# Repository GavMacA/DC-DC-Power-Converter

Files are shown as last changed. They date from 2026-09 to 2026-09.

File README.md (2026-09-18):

# DC-DC-Power-Converter
Complete design of a DC-DC power converter capable of powering a device using a USB-C cable powered by a DC source while adhering to USB Power Delivery specs
The specifications for the design were split in to two domains:

Static:
- Input Voltage Range = 7.5V - 24V
- Output Voltage Range = 5V - 15V
- Max Output Current = 3A
- Max peak-to-peak variation in the winding less than 25% of the max output current
- Max output voltage variation +/- 25mV

Dynamic:
- Response Time less than 1.5ms (to within 5%) during a step from 5V to 12V (Vin = 24V, Rout = 4Ohms)
- Overshoot: Less than 5% during voltage steps
- Load Step Recovery: Voltage error less than 100mV within 1ms after load transition (Vout=5V, Vin=24V, R[load] passes from 3 kOhms to 4 Ohms)
- Max 2.5V overshoot during a load step (from 3A to 0A)

# Project Structure

```bash
DC-DC Power Converter/
├── README.md
├── docs/
│   ├── B5_BALHI_THENOZ_MACAONGHUSA_simu_buck_CREATE_BF.slx
│   ├── B5_BALHI_THENOZ_MACAONGHUSA_simu_buck_CREATE_BO.slx
│   └── main.c   (Microcontroller code)
├── images/
│   ├── BUCK_CL_Simulink
│   ├── BUCK_OL_SIMULINK
│   ├── PCB_Bottom_Lyer.png
│   ├── PCB_Top_Layer.png
│   ├── Physical_Board_Bottom_Layer.jpeg
│   └── Physical_Board_Top_Layer.jpeg
└── Altium/
│   ├── A4_INSAGE_01.SchDoc
│   ├── A4_INSAGE_02.SchDoc
│   ├── A4_INSAGE_03.SchDoc
│   ├── Altium CREATE 2026.PrjPcb
│   ├── Altium_CREATE_2026.IntLib
│   └── PCB1_INSAGE.PcbDoc
```

## Design and size closed loop and open loop Buck Converter using MATLAB Simulink

Using real world RS components available online we sized components to achieve the above specifications with an approximate efficiency of 90% for the open loop design.

<div align="center">

Open Loop Buck

</div>

The closed loop design incorporated an adjustable PID regulator to respond to a change in load size or target output voltage.

<div align="center">

Closed Loop Buck

</div>

## Mapping and Routing of PCB using Altium Designer

<div align="center">

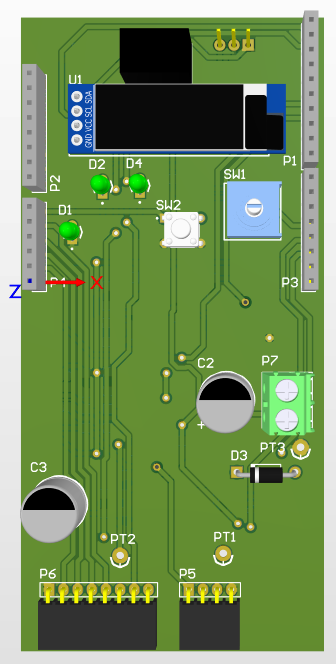
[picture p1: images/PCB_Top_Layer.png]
PCB Top Layer


**PCB Top Layer**

</div>

<div align="center">

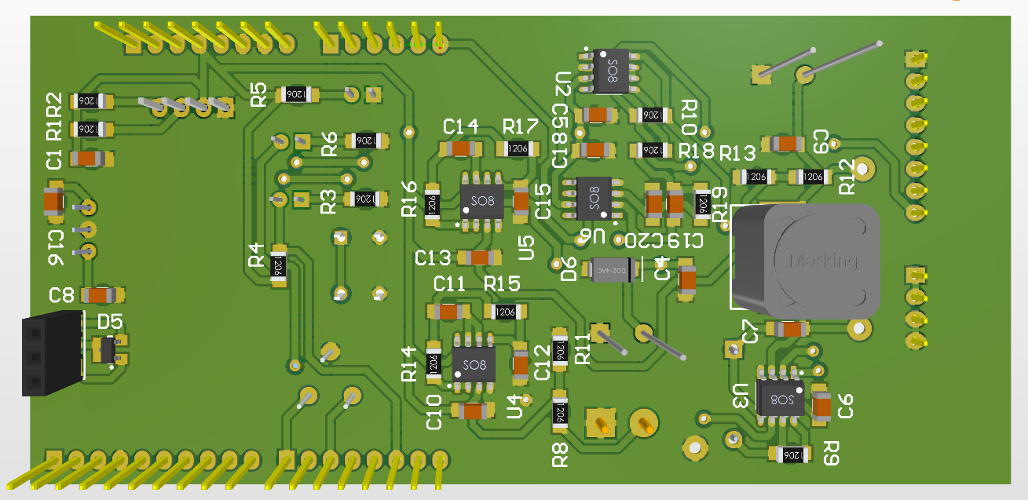
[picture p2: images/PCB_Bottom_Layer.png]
PCB Bottom Layer


**PCB - Bottom Layer**

</div>

## Soldering Standardised routing provided by module coordinators

<div align="center">

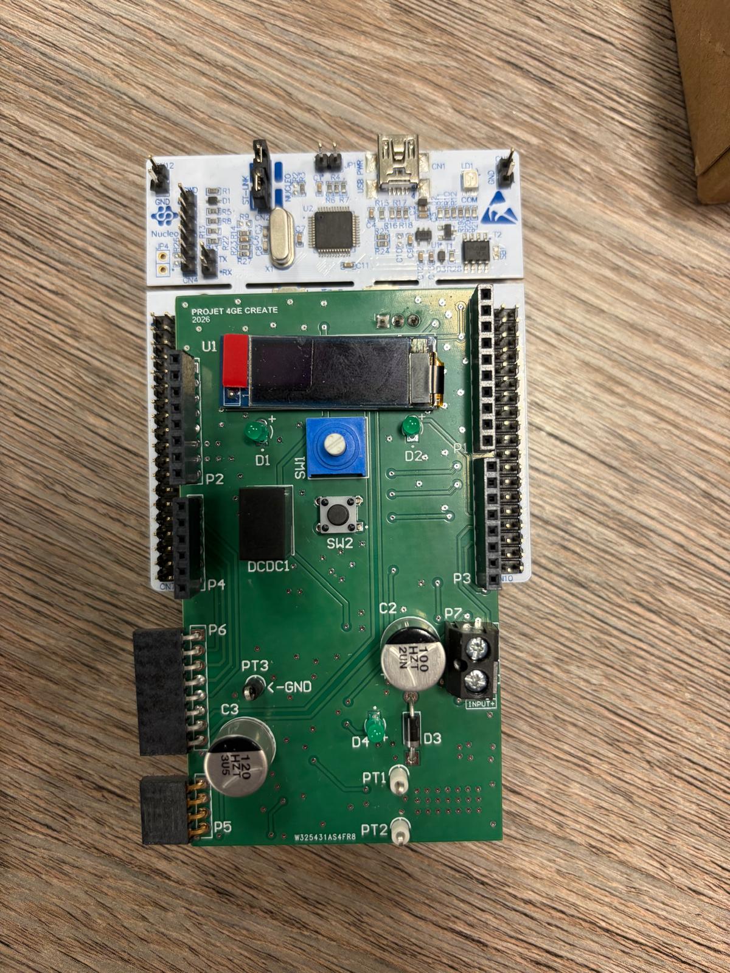
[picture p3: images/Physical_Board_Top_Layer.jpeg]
Board Top Layer


**Board Top Layer**

</div>

<div align="center">

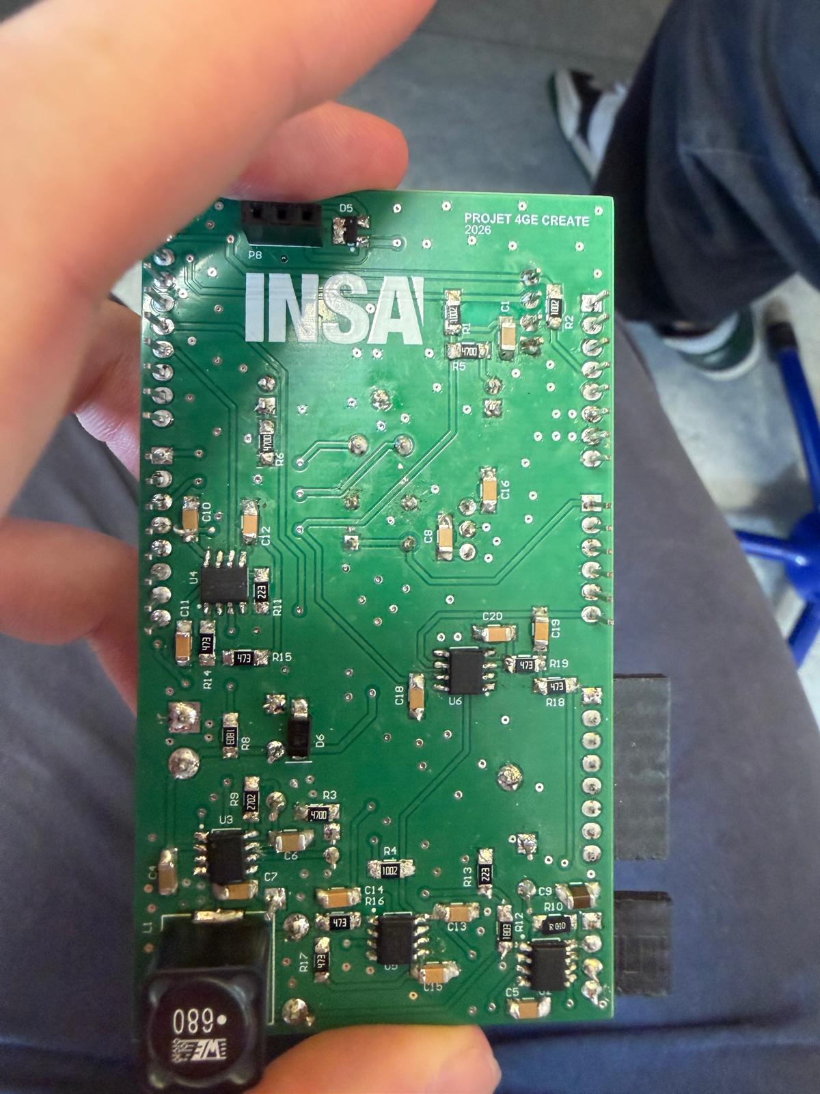
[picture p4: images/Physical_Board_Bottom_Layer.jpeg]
Board Bottom Layer


**Board - Bottom Layer**

</div>

## Modifying STM32Cube microcontroller code using C

The project was generated in STM32CubeIDE/CubeMX; our work was confined to the USER CODE sections of main.c. The final stage of the project gave us several different ideas to focus on when adapting the code. Thus it must be acknowledged that this code is an incomplete prototype. Our focuses were User Interface/Controls, PWM Control, Open and Closed Loop modes and Power Delivery Object mode (PI control used for CL and PDO).

The User interface was implemented using an OLED screen, rotary encoder and button. It offers 4 menus: Display of measurements (Vin, Vout, Iout), Control type (OL, CL, PDO), OL setpoint, CL setpoint (set desired output voltage).

- Open Loop - Calculates duty cycle each period using the current input voltage and the user-selected output voltage, with no feedback from the output.
- Closed Loop - Constantly updates the duty cycle using PI in response to fluctuations in the load size to maintain desired voltage output.
- PDO - The controller negotiates the USB-C contract and the firmware reads the agreed profile (5/9/12/15V) and then the PI maintains this level

Direct Memory Access is used for efficient sampling and the PWM output. The ADC by the internal timer and writes its three channels straight to memory. The PWM duty cycle is streamed from a double-buffered array so it can be updated without disturbing the running output. It is 8 bits (0-255) due to the timer's 256-count period.To reduce computational overhead the PI controller coefficents were scaled up in order to avoid floating point values instead completing integer calculations. 

**Notes/Limitations**
- Much of the code's comments are in French as this project was completed during an ERASMUS programme.
- Sections not chosen under the scope: Energy and Power calculations; overload protection; output filtering

# My Contributions
Most tasks were completed collaboratively, the following our sections I contributed to directly.

- Simulink - Design and testing of open loop buck converter
- Altium - Schematic connections, mapping of PCB layout
- PCB - Soldered surface mounted and through-hole components
- Microcontroller code (C) - PWM configuration and non-technical writing of User-interface 

# Contributors
Matteo Thenoz

Guillaume Balhi

Gavin Mac Aonghusa

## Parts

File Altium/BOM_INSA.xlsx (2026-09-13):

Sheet: BOM Report
Nomenclature
Source : |  | Field=DataSourceFileName
Projet : |  | Field=ProjectFileName
Désignation | Description | SchLib_Id | PcbLib_Id | Valeur | Puissance | Fournisseur 1 | Fournisseur 2
Date d'édition : | 2020-12-18 | 10:35:19

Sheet: Project Information
Project Full Path | Field=ProjectFullPath
Project Filename | Field=ProjectFileName
Variant Name | Field=VariantName
Data-Source Filename | Field=DataSourceFileName
Data-Source Full Path | Field=DataSourceFullPath
Title | Field=Title
Total Quantity | Field=TotalQuantity
Report Time | Field=ReportTime
Report Date | Field=ReportDate
Report Date & Tine | Field=ReportDateTime
Output Name | Field=OutputName
Output Type | Field=OutputType
Output Generator Name | Field=GeneratorName
Output Generator Description | Field=GeneratorDescription

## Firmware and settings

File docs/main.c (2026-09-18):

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
/* Includes ------------------------------------------------------------------*/
#include "main.h"

/* USER CODE BEGIN Includes */
#include <string.h>
#include <stdio.h>
#include <stdbool.h>
#include "ssd1306/ssd1306.h"
/* USER CODE END Includes */

/* USER CODE BEGIN PD */
#define ADC_BUF_LEN 3

#define PWM_BUFFER_SIZE 32
#define PWM_HALFBUFFER_SIZE 16
#define DITHER_RES 8

enum rotary_direction {
	DIRECTION_NONE,
	DIRECTION_CW,
	DIRECTION_CCW,
	NUM_OF_DIRECTIONS
};

/* USER CODE END PD */

ADC_HandleTypeDef hadc;
DMA_HandleTypeDef hdma_adc;

I2C_HandleTypeDef hi2c1;

TIM_HandleTypeDef htim2;
TIM_HandleTypeDef htim22;
DMA_HandleTypeDef hdma_tim2_ch2;

UART_HandleTypeDef huart2;

/* USER CODE BEGIN PV */
static uint8_t rotary_state;
static uint8_t rotary_counter = 0;
static int8_t rotary_direction = DIRECTION_NONE;

uint16_t adc_buf[ADC_BUF_LEN];

// Tramage (dithering)
uint16_t pwm_buffer[PWM_BUFFER_SIZE];
uint8_t pwm_pulse = 0;

//Asservissement / regulation
int32_t integration_sum = 0.0;
uint32_t pwm_pulse_BF = 0;
uint8_t Vref_BF = 0;
// sur chaque valeurs des coeficiant de calcul, on applique un facteur 10 puissance 10 pour manipuler des int
int32_t dt = 256; //la periode d'échantillonage
int32_t Kp  = 500000;
int32_t Ki = 400000;

//variables des mesures de l'ADC
float vin_value =  0.0;
float vout_value = 0.0;
float iout_value = 0.0;

/* USER CODE END PV */

void SystemClock_Config(void);
static void MX_GPIO_Init(void);
static void MX_DMA_Init(void);
static void MX_ADC_Init(void);
static void MX_I2C1_Init(void);
static void MX_USART2_UART_Init(void);
static void MX_TIM2_Init(void);
static void MX_TIM22_Init(void);
/* USER CODE BEGIN PFP */

// State management
void Set_Next_Mode(void);
void Set_Previous_Mode(void);

// Human interface
void Update_Display(void);
bool Button_Pushed(){
	if(HAL_GPIO_ReadPin(GPIOA, Button_Pin) == 0){
		return true;
	}else{
		return false;
	}
}


// USB Power Delivery requests
uint8_t Read_USB_PDO(void);
void Test_STUSB_I2C(void);
void Set_STUSB_Available_Profiles(uint8_t num_profiles);

// Voltage controller
int32_t Compute_control_input(int32_t y_setpoint, int32_t y_value);
void TransferComplete(DMA_HandleTypeDef *hdma);
void TransferHalfComplete(DMA_HandleTypeDef *hdma);

/* USER CODE END PFP */

/**
  * @brief  The application entry point.
  * @retval int
  */
int main(void)
{

  /* MCU Configuration--------------------------------------------------------*/

  /* Reset of all peripherals, Initializes the Flash interface and the Systick. */
  HAL_Init();

  /* Configure the system clock */
  SystemClock_Config();

  /* Initialize all configured peripherals */
  MX_GPIO_Init();
  MX_DMA_Init();
  MX_ADC_Init();
  MX_I2C1_Init();
  MX_USART2_UART_Init();
  MX_TIM2_Init();
  MX_TIM22_Init();
  /* USER CODE BEGIN 2 */

	// Initialize screen
	ssd1306_Init();
	ssd1306_Fill(Black);
	ssd1306_UpdateScreen();

	//  HAL_TIM_PWM_Start(&htim2,TIM_CHANNEL_3);
	HAL_ADC_Start_DMA(&hadc, (uint32_t*) adc_buf, ADC_BUF_LEN);

	// Start PWM timer
	HAL_TIM_PWM_Start_DMA(&htim2, TIM_CHANNEL_2, (uint32_t*) pwm_buffer, PWM_BUFFER_SIZE);

	// Start main timer
	htim2.hdma[TIM_DMA_ID_CC2]->XferCpltCallback = TransferComplete;
	htim2.hdma[TIM_DMA_ID_CC2]->XferHalfCpltCallback = TransferHalfComplete;
	HAL_TIM_Base_Start_IT(&htim22);

	// Switch off user LED
	HAL_GPIO_WritePin(LED_GPIO_Port, LED_Pin, 0);

  /* USER CODE END 2 */

  /* Infinite loop */
  /* USER CODE BEGIN WHILE */

	// TODO
	// 1.1 Menu et navigation


	//déclaration des variables utilisateur
	uint8_t Vout_BO = 0;
	uint8_t Vout_BF = 0;
	uint8_t type_commande = 2; // 0 = BO, 1 = BF, 2 = PDO

	// définition des variable pour l'affichage des mesures
	int vin_value_int_u = 0;
	int vin_value_int_d = 0;

	int vout_value_int_u = 0;
	int vout_value_int_d = 0;

	int iout_value_int_u = 0;
	int iout_value_int_d = 0;


	//déclaration des variable définissant les modes d'utilisations des différents menus (mode 0 = affichage, mode 1 = modification)
	uint8_t mode = 0;
	uint8_t menu = 0;

	//déclaration du numéro de menu max ategnable
	int menu_max = 3;

	//déclaration des variables texte que l'on affichera sur l'écran
	char line1_str[20] = {0};
	char line2_str[20] = {0};
	char line3_str[20] = {0};

	while (1)
	{
    /* USER CODE END WHILE */

    /* USER CODE BEGIN 3 */

		//les lignes de code suivante permettent de gérer les différent menus de l'IHM
		//dans l'ordre, les menus permettent de :
		//afficher les valeurs mesurée des tensions et courants
		//selectionner le type de commande que l'on veut pour notre convertisseur (BO, BF ou PDO)
		//définir les paramètre de la commande en Boucle ouverte
		//définir les paramètre de la commande en Boucle fermé

		//L'interface à 2 modes différent, un mode de sélection de menu, et un mode de définission des paramètres.

		//pour le premier mode de sélection des menus :
		if(mode == 0){
			// premier menu, affichage du courant et des tensions mesurées
			if(rotary_counter == 0){
				sprintf(line1_str, "affichage mesures ", rotary_counter);
				sprintf(line2_str, "Ve:%02u,%02u Vs:%02u,%02u ", vin_value_int_u, vin_value_int_d, vout_value_int_u, vout_value_int_d);
				sprintf(line3_str, "Io:%02u,%03u         ", iout_value_int_u, iout_value_int_d);
			}
			// deuxième menu, selection du type de commande
			if(rotary_counter == 1){

				sprintf(line1_str, "Selection commande");
				sprintf(line2_str, "                   ");

				if(type_commande == 0){
					sprintf(line3_str, "Commande = BO     ");
				}
				if(type_commande == 1){
					sprintf(line3_str, "Commande = BF     ");
				}
				if(type_commande == 2){
					sprintf(line3_str, "Commande = PDO    ");
				}
				//si le boutton est pressé, on passe au mode de modification de la valeur
				if(Button_Pushed()){
					for(int i=0; i<100000; i++);
					while(Button_Pushed());
					for(int i=0; i<100000; i++);
					mode = 1;
					menu = 1;
					rotary_counter = type_commande;
				}
			}
			// troisième menu, selection des paramètre de la commande en boucle ouverte
			if(rotary_counter == 2){

				sprintf(line1_str, "Boucle Ouverte    ");
				sprintf(line2_str, "                  ");
				sprintf(line3_str, "Vout = %02u         ", Vout_BO);
				//si le boutton est pressé, on passe au mode de modification de la valeur
				if(Button_Pushed()){
					for(int i=0; i<100000; i++);
					while(Button_Pushed());
					for(int i=0; i<100000; i++);
					mode = 1;
					menu = 2;
					rotary_counter = Vout_BO;
				}
			}
			// quatrième menu, selection des paramètre de la commande en boucle fermée
			if(rotary_counter == 3){

				sprintf(line1_str, "Boucle Fermee     ");
				sprintf(line2_str, "                  ");
				sprintf(line3_str, "Vout = %02u         ", Vout_BF);
				//si le boutton est pressé, on passe au mode de modification de la valeur
				if(Button_Pushed()){
					for(int i=0; i<100000; i++);
					while(Button_Pushed());
					for(int i=0; i<100000; i++);
					mode = 1;
					menu = 3;
					rotary_counter = Vout_BF;
				}
			}

			// si on dépasse le quatrième menu, on reviens au premier menu
			if(rotary_counter > menu_max){
				rotary_counter = 0;
			}

		}

		//pour le deuxième mode de modifications des valeurs
		if(mode == 1){
			// on peu modifier la valeur du type de la commande (deuxième menu)
			if(menu == 1){
				sprintf(line1_str, "Selection commande");
				sprintf(line2_str, "                  ");

				if(rotary_counter == 0){
					sprintf(line3_str, "Commande = [BO]   ");
					type_commande = 0;
				}
				if(rotary_counter == 1){
					sprintf(line3_str, "Commande = [BF]   ");
					type_commande = 1;
				}
				if(rotary_counter == 2){
					sprintf(line3_str, "Commande = [PDO]  ");
					type_commande = 2;
				}

				if(rotary_counter > 2){
					rotary_counter = 2;
				}
				if(Button_Pushed()){
					for(int i=0; i<100000; i++);
					while(Button_Pushed());
					for(int i=0; i<100000; i++);
					mode = 0;
					rotary_counter = menu;
				}

			}
			// on peu modifier la valeur de la tension désirée pour la commande en boucle ouverte (troisième menu)
			if(menu == 2){
				sprintf(line1_str, "Boucle Ouverte    ");
				sprintf(line2_str, "                  ");
				sprintf(line3_str, "Vout = [%02u]       ", Vout_BO);
				Vout_BO = rotary_counter;
				if(rotary_counter > 15){
					rotary_counter = 15;
				}
				if(Button_Pushed()){
					for(int i=0; i<100000; i++);
					while(Button_Pushed());
					for(int i=0; i<100000; i++);
					mode = 0;
					rotary_counter = menu;
				}
			}
			// on peu modifier la valeur de la tension désirée pour la commande en boucle fermée (quatrième menu)
			if(menu == 3){
				sprintf(line1_str, "Boucle Fermée     ");
				sprintf(line2_str, "                  ");
				sprintf(line3_str, "Vout = [%02u]       ", rotary_counter);
				if(rotary_counter > 15){
					rotary_counter = 15;
				}
				if(Button_Pushed()){
					for(int i=0; i<100000; i++);
					while(Button_Pushed());
					for(int i=0; i<100000; i++);
					Vout_BF = rotary_counter;
					mode = 0;
					rotary_counter = menu;
				}
			}
		}

		// TODO
		// 2.1 Conversion Analogique-Numérique
		// 2.2 Etalonage

		// dans les lignes suivante, on viens diviser les valeurs de type float en valeurs de type int, affichable à l'écran.
		vin_value_int_u = (int)vin_value;
		vin_value_int_d = (int)((vin_value - vin_value_int_u)*100);

		vout_value_int_u = (int)vout_value;
		vout_value_int_d = (int)((vout_value - vout_value_int_u)*100);

		iout_value_int_u = (int)iout_value;
		iout_value_int_d = (int)((iout_value - iout_value_int_u)*1000);

		// TODO
		// 3.1 Gestion PWM
		if(type_commande == 0){
			// Convertit la valeur voulu de Vout en une valeur du rapport cyclique (entre 0 et 255)
			// 16 bit pour gérer la valeur max : 255
			pwm_pulse = (((float)Vout_BO/(float)vin_value) * 255.0);
		}

		if(type_commande == 1){
			// Si nous voulons une commande en boucle fermé, nous utilisons la fonction de calcul
			// du rapport cyclique qui viens le modifier en temps réel en fonction de Vout voulu et Vout mesuré (décidé par l'utilisateur).
			Vref_BF = Vout_BF;
			pwm_pulse = ((float)pwm_pulse_BF/100000000.0)*255.0;
		}

		// TODO
		// 4.1 Lecture PDO et asservissement

		if(type_commande == 2){
			// Si nous voulons une commande en PDO, nous utilisons la fonction de calcul
			// du rapport cyclique qui viens le modifier en temps réel en fonction de Vout voulu et Vout mesuré (décidé en fonction des broches de communication de la sortie).

			//si le pin PDO5 est mis au GND, on demande 9V
			if(HAL_GPIO_ReadPin(GPIOA, PDO2_Pin) < 0.5){
				Vref_BF = 9;
				HAL_GPIO_WritePin(LED_GPIO_Port, LED_Pin, 1);
			}
			//si le pin PDO4 est mis au GND, on demande 12V
			else if(HAL_GPIO_ReadPin(GPIOA, PDO3_Pin) < 0.5){
				Vref_BF = 12;
			}
			//si le pin PDO3 est mis au GND, on demande 15V
			else if(HAL_GPIO_ReadPin(GPIOB, PDO4_Pin) < 0.5){
				Vref_BF = 15;
			}
			//si aucun pin est mis au GND, on demande 5V
			else{
				Vref_BF = 5;
			}
			pwm_pulse = ((float)pwm_pulse_BF/100000000.0)*255.0;
			HAL_GPIO_WritePin(LED_GPIO_Port, LED_Pin, 0);
		}

//HAL_GPIO_ReadPin(PDO5_GPIO_Port, PDO5_Pin)




		// TODO
		// 2.3 Calcul énergie et Puissance

		// rafraichissement de l'écran en fonction des variable de texte modifié précédement !
		ssd1306_SetCursor(0, 0);
		ssd1306_WriteString(line1_str, Font_7x10, White);
		ssd1306_SetCursor(0, 11);
		ssd1306_WriteString(line2_str, Font_7x10, White);
		ssd1306_SetCursor(0, 21);
		ssd1306_WriteString(line3_str, Font_7x10, White);
		ssd1306_UpdateScreen();

		// Delay
		HAL_Delay(25);
	}
  /* USER CODE END 3 */
}

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
/* USER CODE BEGIN 4 */

/*** IHM ***/


/*** USB Power Delivery Objects ***/


void Test_STUSB_I2C(void)
{
	char msg[60];
	uint8_t id;
	// Device I2C address : 0x28
	// Device ID register : 0x2F
	int ret = HAL_I2C_Mem_Read(&hi2c1, (0x28 << 1), 0x70, 1, &id, 1, 0xFFFFFFFF);
	if (ret == HAL_OK)
	{
		sprintf(msg, "STUSB I2C test success\r\n");
	}
	else
	{
		sprintf(msg, "STUSB I2C test error %d\r\n", ret);
	}
	HAL_UART_Transmit(&huart2, (uint8_t*)msg, strlen(msg), HAL_MAX_DELAY);
}

void Set_STUSB_Available_Profiles(uint8_t num_profiles)
{
	// TODO
	// 4.3 Programmation PDOs

	/** Documentation for write number of available profiles
	 * I2C communication:
	 * Use HAL_I2C_Mem_Read and HAL_I2C_Mem_Write functions to directly read/write into register
	 * WRN: Device address is 0x28 but should be passed shifted (0x28 << 1) to those functions
	 * Cf. Test_STUSB_I2C function
	 *
	 * Register 0x70 DPM_PDO_NUMB
	 * bit [7:5] DPM_SRC_PDO_NUMB <--- Number of source profiles available
	 * bit [4:3] reserved
	 * bis [2:0] DPM_SNK_PDO_NUMB
	 *
	 * Procedure :
	 * 1) Set device into reset state : write 0x01 to register 0x23
	 * 2) Write new value to regsiter 0x70, for ex. 0xA3 to set all 5 profiles available (1010001)
	 * Or write for example 0x23 to set only one profile available (00100011)
	 * 3) Set device back to normal mode : write 0x04 to register 0x23
	 */
}

/*** Voltage controller ***/

int32_t Compute_control_input(int32_t yref, int32_t y)
{
	// TODO
	// 3.2 Régulation

	int32_t current_error = yref-y;
	integration_sum += (current_error*dt)/1000000;

	if(integration_sum >= 2147483648){
		integration_sum = 2147483648;
	}
	if(integration_sum <= -2147483648){
		integration_sum = -2147483648;
	}

	int64_t output_64;
	output_64 =  (Kp*current_error/10000 + (Ki/10000)*integration_sum);
	int32_t output = (int32_t)output_64;

	if(output >= 100*1000000){ //100000000
		output = 100*1000000;
	}
	if(output <= 0){
			output = 0;
		}

	return output;


}

/*******************************************************************
 * INTERRUPTS
 *******************************************************************/

void HAL_ADC_ConvCpltCallback(ADC_HandleTypeDef* hadc)
{

	//TODO
	// 2.1 Conversion Analogique-Numérique
	// 2.2 Etalonage

	// calcul des valeurs de tension et de courant en fonction des valeurs numérique de l'ADC.
	// on divise par 4096 car l'ADC est sur 12 bits
	// on multiplie par 3.3 car c'est la tension pleine échelle
	// les valeurs 22 et 180 coresponde, en kilo ohms, au valeurs des résistances des ponts diviseurs de tensions (ces calcul permettent de prendre en compte la modification que le pont induit)
	vin_value =  ((((22+180)*adc_buf[1]/22)*3.3)/4096)-0.35;
	vout_value = ((((22+180)*adc_buf[0]/22)*3.3)/4096)-0.45;
	//iout_value = -((adc_buf[2]/2000)*3.3/4096)+3.3;
	iout_value = (-((adc_buf[2])*3.3/4096)+3.3)*4.4;

	//TODO
	//3.2 Régulation

	//On calcule de nouveau alpha à chaque mesure des tension de sortie et d'entrée, on le place dans une variable global.
	int vout_value_int_u = (int)vout_value;
	int vout_value_int_d = (int)((vout_value - vout_value_int_u)*100);
	pwm_pulse_BF = (Compute_control_input((Vref_BF*1000000), (vout_value_int_u*100 + vout_value_int_d)*10000));


	// TODO
	// 4.2 Protection
}

void TransferComplete(DMA_HandleTypeDef *hdma)
{
	//TODO
	// 3.3 Filtrage sortie

	for(int i=0;i<PWM_HALFBUFFER_SIZE;i++)
	{
		pwm_buffer[i+PWM_HALFBUFFER_SIZE] = pwm_pulse;
	}
}

void TransferHalfComplete(DMA_HandleTypeDef *hdma)
{
	//TODO
	// 3.3 Filtrage sortie

	for(int i=0;i<PWM_HALFBUFFER_SIZE;i++)
	{
		pwm_buffer[i] =  pwm_pulse;

	}
}

void Rotary_Encoder_Interrupt_Handler(void)
{
	static int8_t rotary_buffer = 0;
	/* Check for rotary encoder turned clockwise or counter-clockwise */
	uint8_t rotary_new = HAL_GPIO_ReadPin(ROT_CHA_GPIO_Port, ROT_CHA_Pin) << 1;
	rotary_new += HAL_GPIO_ReadPin(ROT_CHB_GPIO_Port, ROT_CHB_Pin);
	if (rotary_new != rotary_state) {
		if (((rotary_state == 0b00) && (rotary_new == 0b10)) || ((rotary_state == 0b10) && (rotary_new == 0b11)) ||
				((rotary_state == 0b11) && (rotary_new == 0b01)) || ((rotary_state == 0b01) && (rotary_new == 0b00))) {
			rotary_buffer ++;
		}
		if (((rotary_state == 0b00) && (rotary_new == 0b01)) || ((rotary_state == 0b01) && (rotary_new == 0b11)) ||
				((rotary_state == 0b11) && (rotary_new == 0b10)) || ((rotary_state == 0b10) && (rotary_new == 0b00))) {
			rotary_buffer --;
		}
		rotary_state = rotary_new;
		/* Filter rotation due to high number of positions */
		if (rotary_buffer > 3) {
			rotary_counter ++;
			rotary_direction = DIRECTION_CW;
			rotary_buffer = 0;
		}
		if (rotary_buffer < -3) {
			rotary_counter --;
			rotary_direction = DIRECTION_CCW;
			rotary_buffer = 0;
		}
	}
}

/* USER CODE END 4 */
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


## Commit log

2026-09-10 Expand README with design specifications
    Added detailed specifications for static and dynamic performance of the DC-DC power converter.
2026-09-13 Rename Screenshot 2026-09-13 144059.png to images/BUCK_OL_Simulink
2026-09-13 Rename Screenshot 2026-09-13 144442.png to images/BUCK_CL_Simulink
2026-09-13 Insert images for Buck Converter designs in README
    Added images for open loop and closed loop Buck Converter designs.
2026-09-13 Insert Closed Loop Buck image in README
    Added an image of the Closed Loop Buck design to the README.
2026-09-13 Rename Altium CREATE 2026.PrjPcb to Altium/Altium CREATE 2026.PrjPcb
    [Altium CREATE 2026.PrjPcb]
2026-09-13 Add section on modifying ESP32 microcontroller code
2026-09-18 Fix load step recovery error and enhance README clarity
    Corrected load step recovery voltage error and improved clarity in the project description.
2026-09-18 Update README to reflect Altium project files
    Replaced KiCad files with Altium files in the documentation.

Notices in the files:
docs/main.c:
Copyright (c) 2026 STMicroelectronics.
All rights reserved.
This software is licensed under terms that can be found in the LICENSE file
